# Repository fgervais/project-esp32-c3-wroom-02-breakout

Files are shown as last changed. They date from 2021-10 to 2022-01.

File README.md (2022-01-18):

# ESP32-C3-WROOM-02-N4 Breakout Board

## Objective

Make a low cost ESP32-C3 board that can run efficiently from 3x AA lithium
batteries.

## Power Consumption

### Deep Sleep (WROOM only)

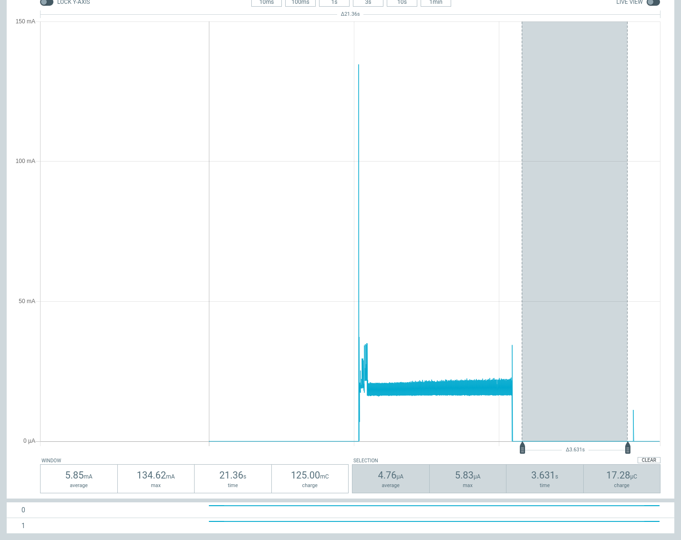
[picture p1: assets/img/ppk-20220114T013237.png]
DeepSleep


Watch the video (https://youtu.be/k5Rf_2-tnsE)

## Price

## PCB

## BOM

### Firmware

https://github.com/fgervais/project-idf-c3-test/tree/master/first_arduino_test

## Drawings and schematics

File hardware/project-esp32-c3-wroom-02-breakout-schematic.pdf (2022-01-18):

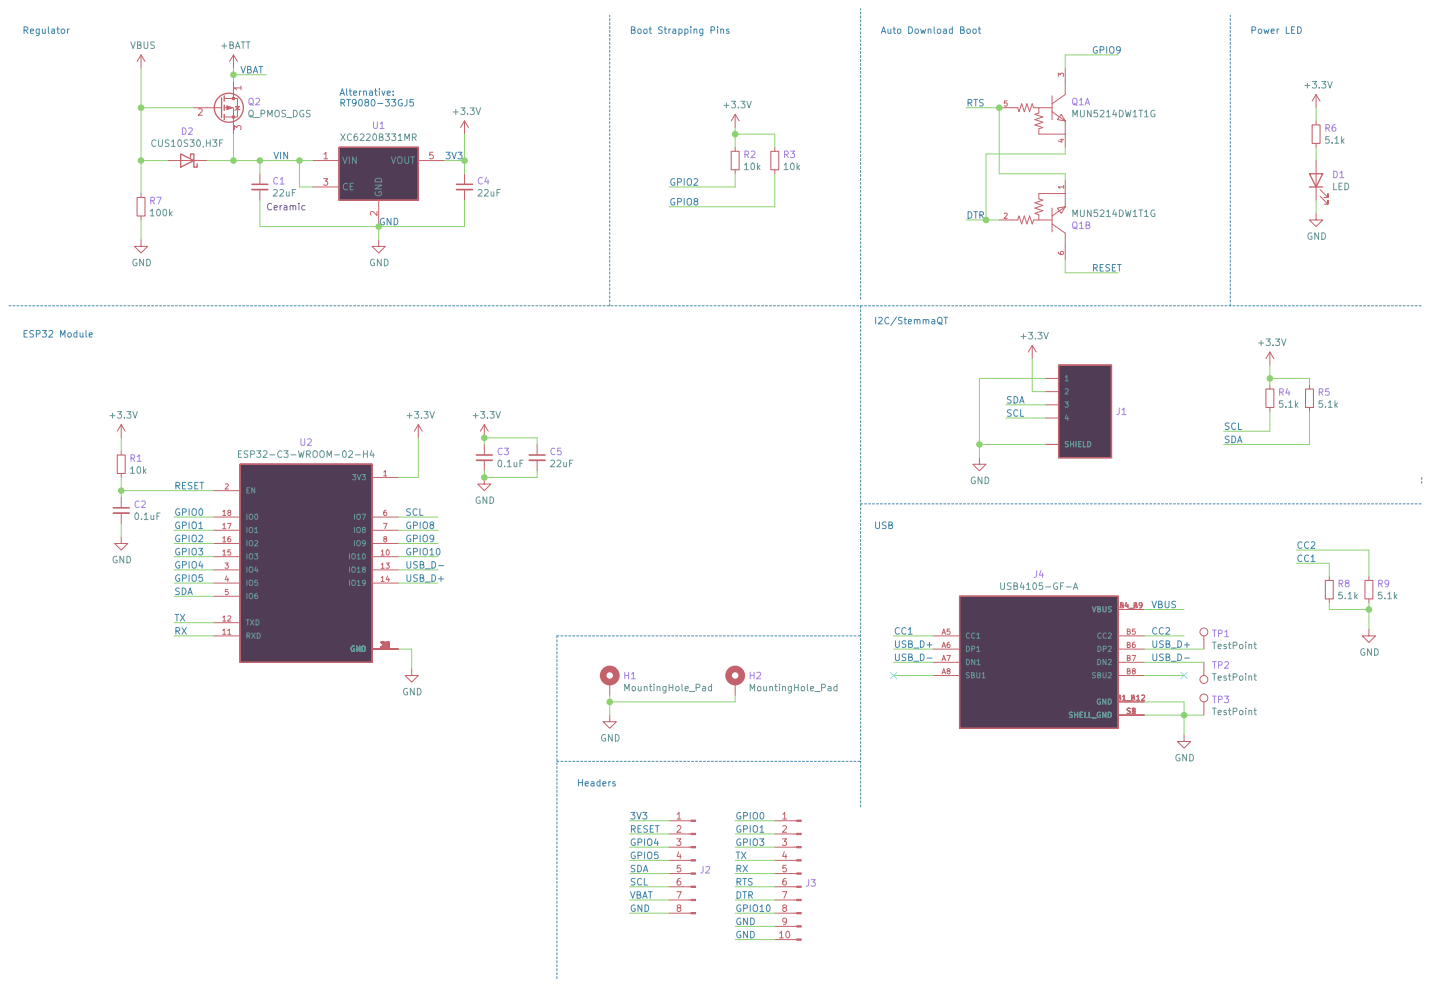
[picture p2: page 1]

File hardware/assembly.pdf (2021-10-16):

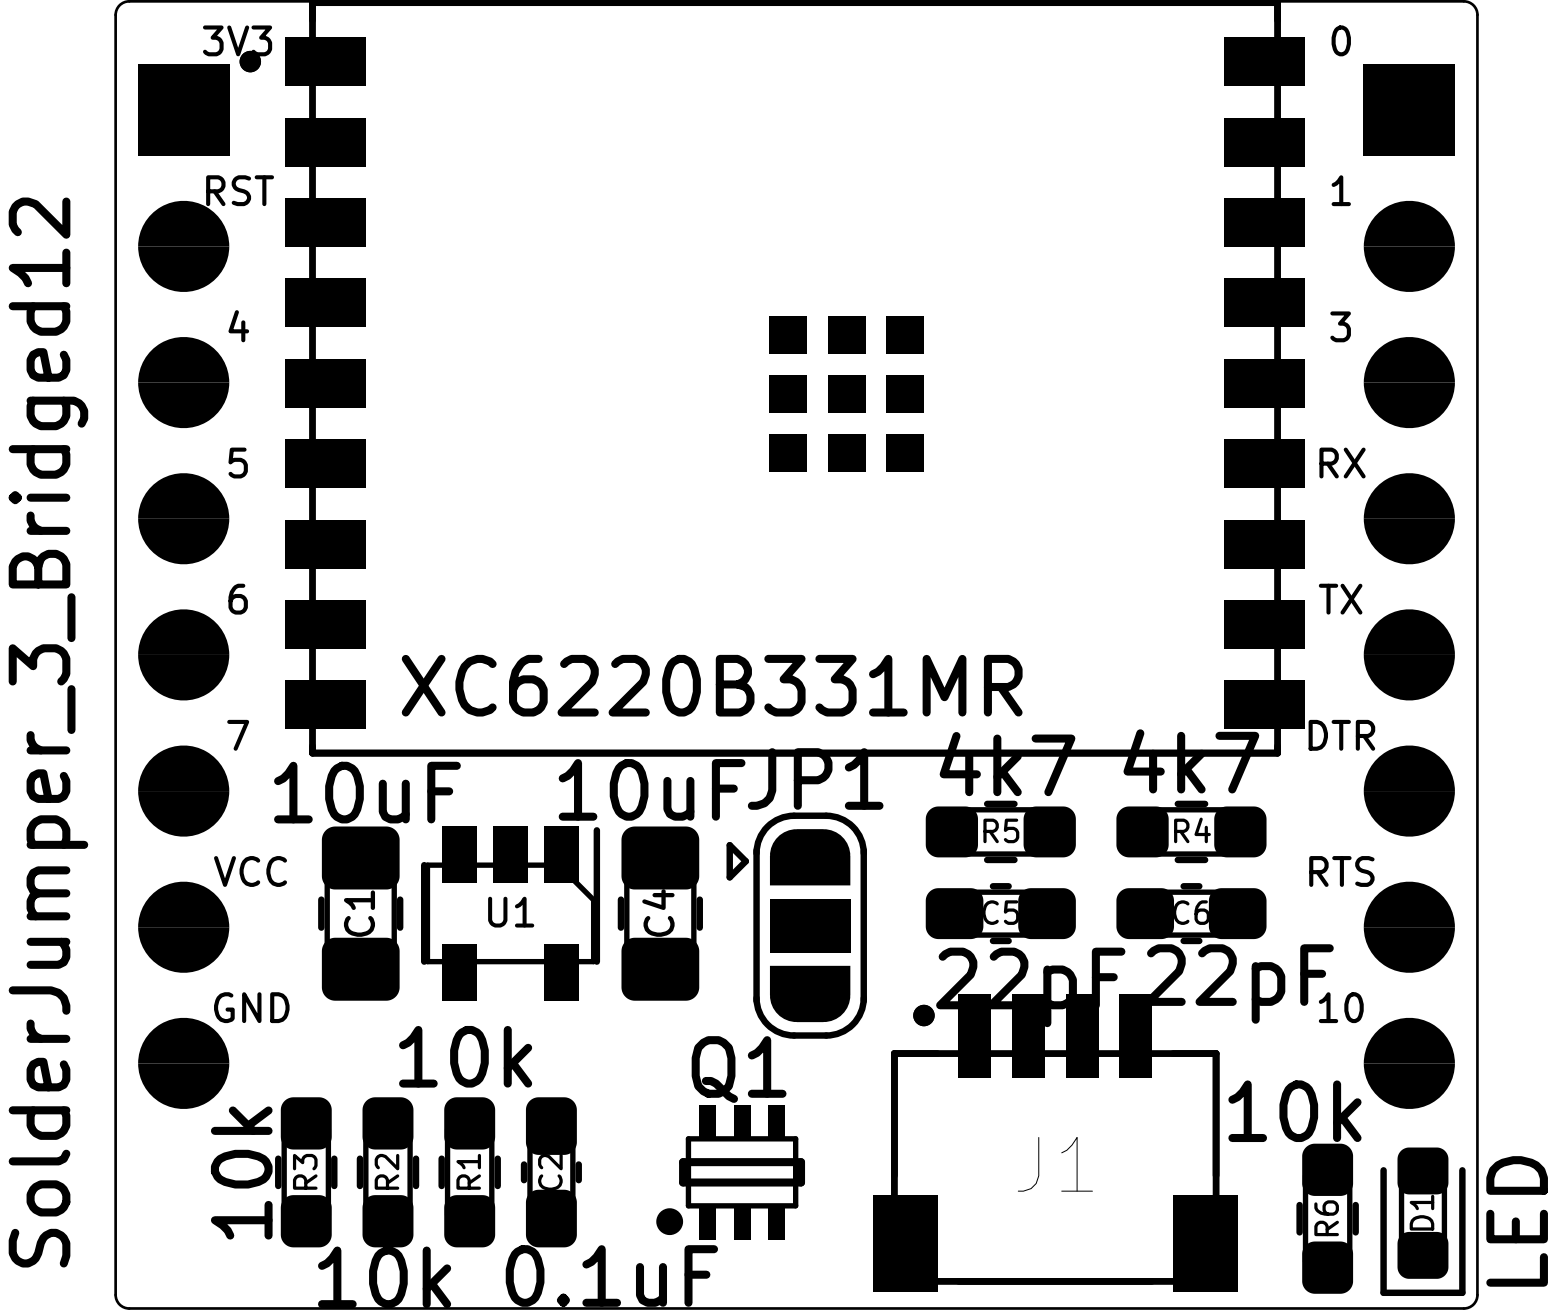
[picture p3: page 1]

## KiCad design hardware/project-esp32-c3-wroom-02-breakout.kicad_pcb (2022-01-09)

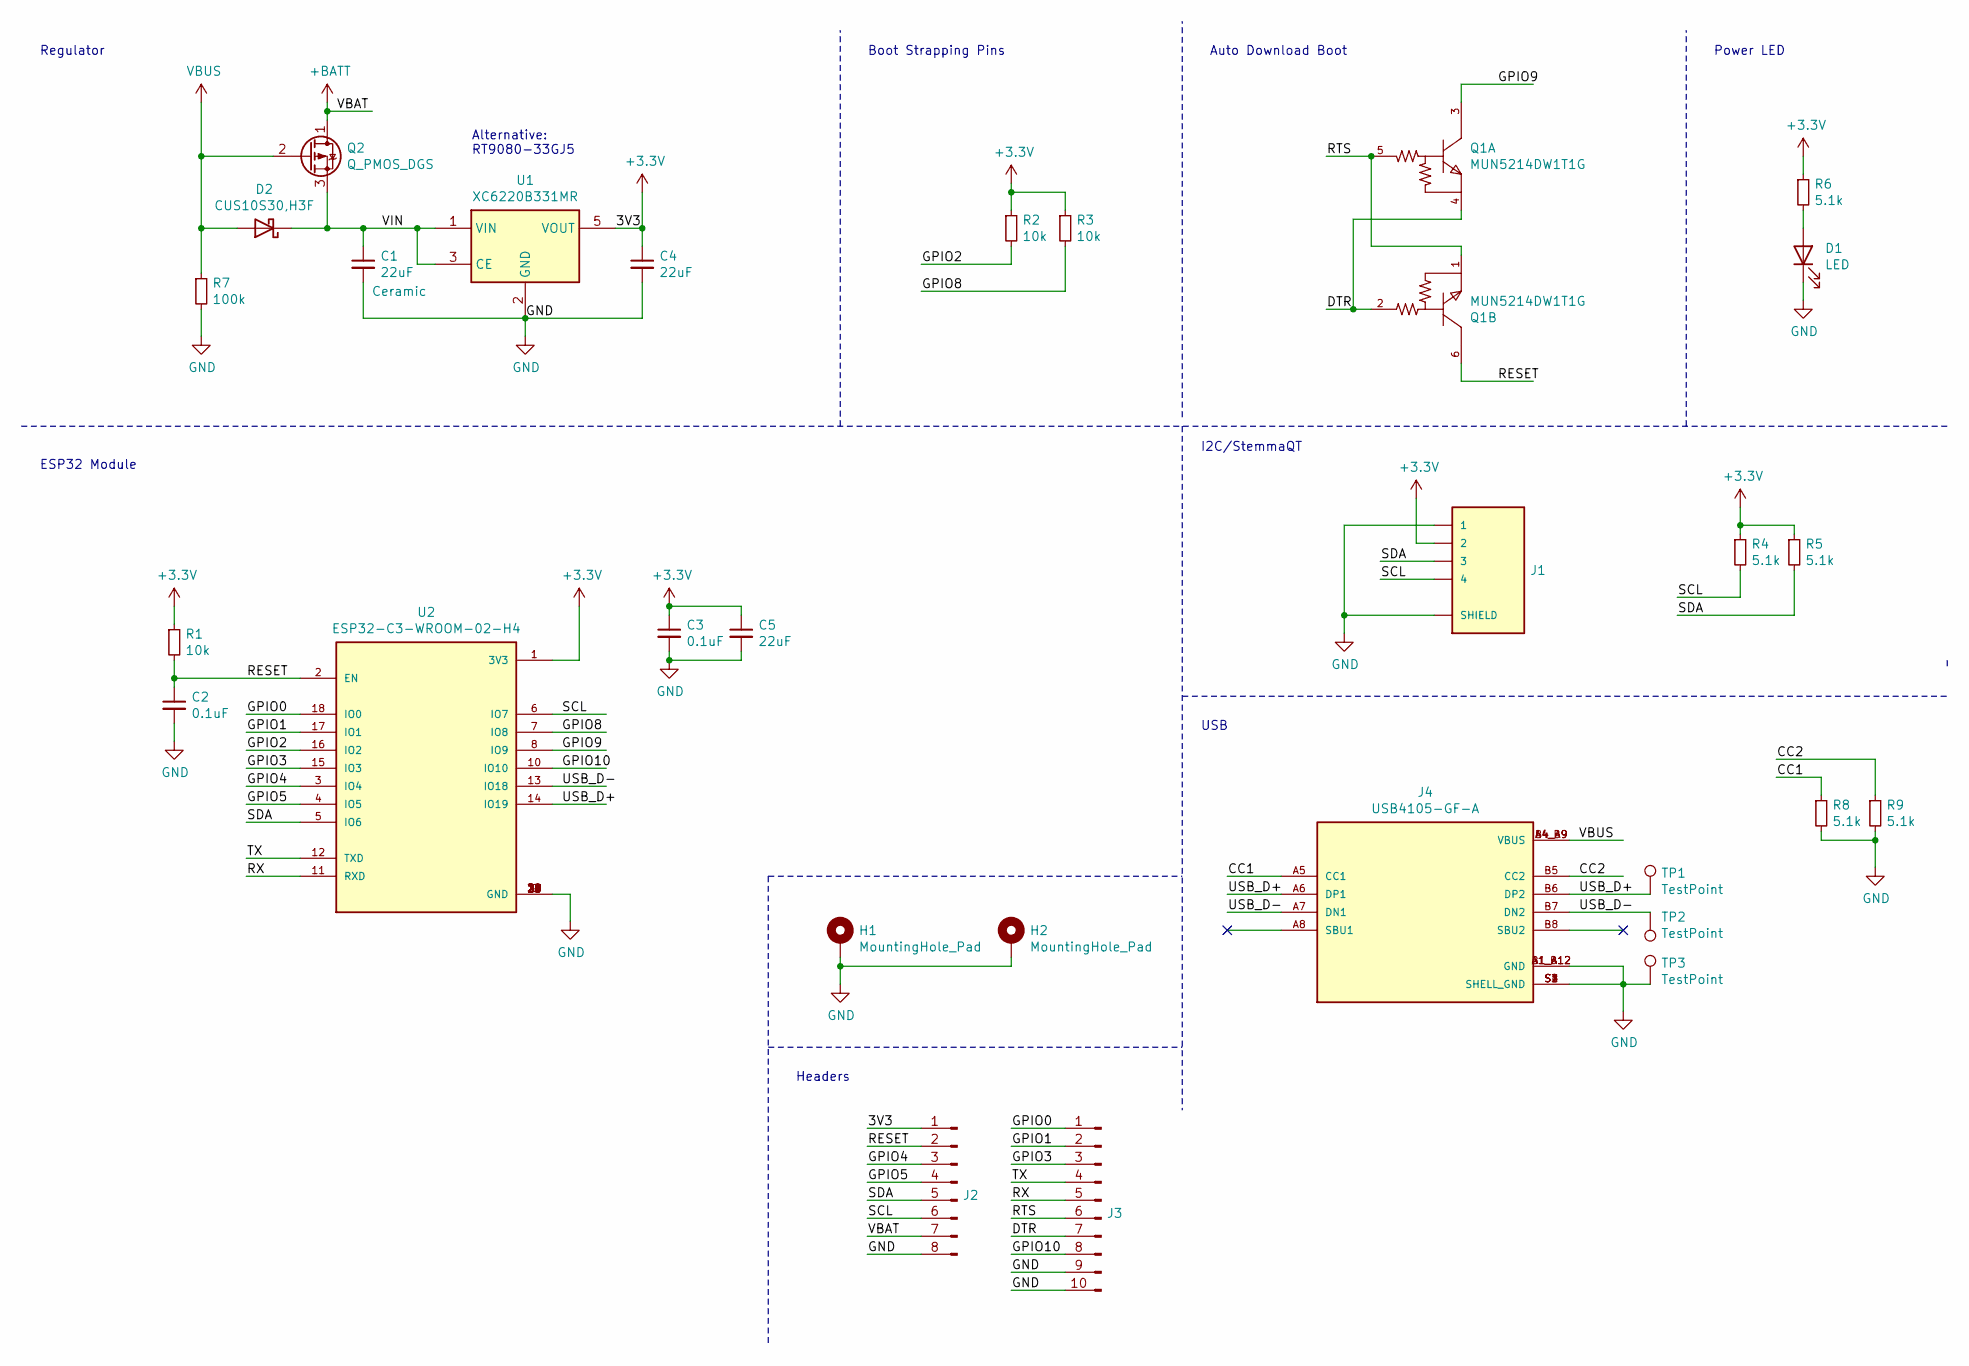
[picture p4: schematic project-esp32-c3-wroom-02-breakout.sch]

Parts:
C1, C4, C5: 22uF; C_0805_2012Metric_Pad1.18x1.45mm_HandSolder
C2, C3: 0.1uF; C_0603_1608Metric_Pad1.08x0.95mm_HandSolder
D1: LED; LED_0603_1608Metric
D2: CUS10S30,H3F‎; D_SOD-323
H1, H2: MountingHole_Pad; MountingHole_2.2mm_M2_ISO7380_Pad
J1: SM04B-SRSS-TB(LF)(SN); JST_SM04B-SRSS-TB(LF)(SN)
J2: Conn_01x08_Male; PinHeader_1x08_P2.54mm_Vertical
J3: Conn_01x10_Male; PinHeader_1x10_P2.54mm_Vertical
J4: USB4105-GF-A; GCT_USB4105-GF-A; PARTREV A3
Q1: MUN5214DW1T1G; On_Semiconductor-MUN5214DW1T1G-Manufacturer_Recommended
Q2: Q_PMOS_DGS; SOT50P160X60-6N
R1, R2, R3: 10k; R_0603_1608Metric_Pad0.98x0.95mm_HandSolder
R4, R5, R6, R8, R9: 5.1k; R_0603_1608Metric_Pad0.98x0.95mm_HandSolder
R7: 100k; R_0603_1608Metric_Pad0.98x0.95mm_HandSolder
TP1, TP2, TP3: TestPoint; TestPoint_Pad_D1.0mm
U1: XC6220B331MR; SOT-23-5
U2: ESP32-C3-WROOM-02-H4; MODULE_ESP32-C3-WROOM-02-H4; PARTREV V1.0

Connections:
+3V3: C3.1, C4.1, C5.1, J1.2, J2.1, R1.1, R2.1, R3.1, R4.1, R5.1, R6.1, U1.5 (VOUT), U2.1 (3V3)
+BATT: J2.7, Q2.1 (D)
/CC1: J4.A5 (CC1), R8.1
/CC2: J4.B5 (CC2), R9.1
/DTR: J3.7, Q1.2 (B), Q1.4 (E)
/GPIO0: J3.1, U2.18 (IO0)
/GPIO1: J3.2, U2.17 (IO1)
/GPIO2: R2.2, U2.16 (IO2)
/GPIO3: J3.3, U2.15 (IO3)
/GPIO4: J2.3, U2.3 (IO4)
/GPIO5: J2.4, U2.4 (IO5)
/GPIO8: R3.2, U2.7 (IO8)
/GPIO9: Q1.3 (C), U2.8 (IO9)
/GPIO10: J3.8, U2.10 (IO10)
/RESET: C2.1, J2.2, Q1.6 (C), R1.2, U2.2 (EN)
/RTS: J3.6, Q1.1 (E), Q1.5 (B)
/RX: J3.5, U2.11 (RXD)
/SCL: J1.4, J2.6, R4.2, U2.6 (IO7)
/SDA: J1.3, J2.5, R5.2, U2.5 (IO6)
/TX: J3.4, U2.12 (TXD)
/USB_D+: J4.A6 (DP1), J4.B6 (DP2), TP1.1, U2.14 (IO19)
/USB_D-: J4.A7 (DN1), J4.B7 (DN2), TP2.1, U2.13 (IO18)
/VIN: C1.1, D2.1 (K), Q2.3 (S), U1.1 (VIN), U1.3 (CE)
GND: C1.2, C2.2, C3.2, C4.2, C5.2, D1.1 (K), H1.1, H2.1, J1.1, J1.S1 (SHIELD), J1.S2 (SHIELD), J2.8, J3.9, J3.10, J4.A1_B12 (GND), J4.B1_A12 (GND), J4.S1 (SHELL_GND), J4.S2 (SHELL_GND), J4.S3 (SHELL_GND), J4.S4 (SHELL_GND), R7.2, R8.2, R9.2, TP3.1, U1.2 (GND), U2.9 (GND), U2.19 (GND), U2.20 (GND), U2.21 (GND), U2.22 (GND), U2.23 (GND), U2.24 (GND), U2.25 (GND), U2.26 (GND), U2.27 (GND), U2.28 (GND), U2.29 (GND), U2.30 (GND), U2.31 (GND), U2.32 (GND), U2.33 (GND), U2.34 (GND), U2.35 (GND), U2.36 (GND), U2.37 (GND), U2.38 (GND), U2.39 (GND)
unnamed: D1.2 (A), R6.2
VBUS: D2.2 (A), J4.A4_B9 (VBUS), J4.B4_A9 (VBUS), Q2.2 (G), R7.1

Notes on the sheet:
Regulator
Boot Strapping Pins
Auto Download Boot
Headers
ESP32 Module
I2C/StemmaQT
Power LED
USB
Alternative: ‎RT9080-33GJ5‎

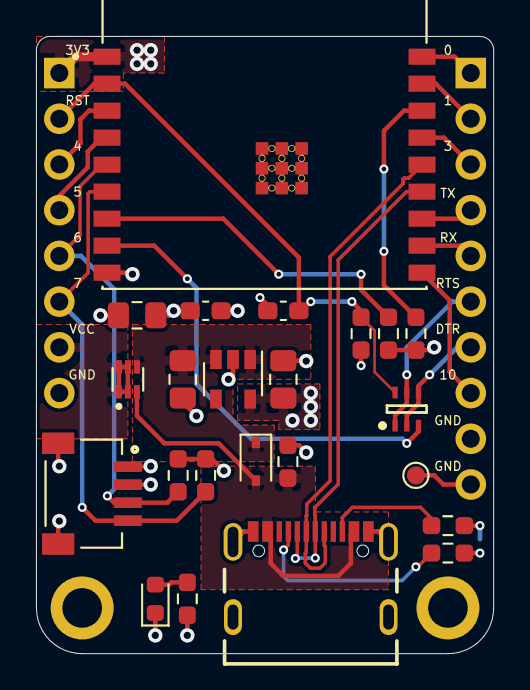
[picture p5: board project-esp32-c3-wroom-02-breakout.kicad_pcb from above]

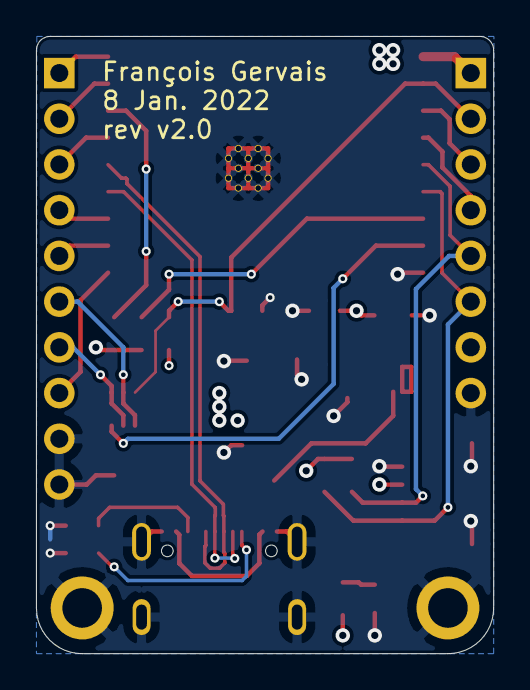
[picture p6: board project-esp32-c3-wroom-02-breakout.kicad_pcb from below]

Board: 4 copper layers, 25.4 x 34.3 mm, 27 parts (2 on the bottom side), 26 nets.

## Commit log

2021-09-17 Use wrover breakout project as base
    [esp32-wrover-breakout.kicad_pcb, esp32-wrover-breakout.sch, project-esp32-c3-wroom-02-breakout.kicad_pcb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]
2021-09-24 Schematic ready
    [project-esp32-c3-wroom-02-breakout.sch]
2021-09-25 First placement done
    [project-esp32-c3-wroom-02-breakout.kicad_pcb, project-esp32-c3-wroom-02-breakout.sch]
2021-09-25 Routing done
    [project-esp32-c3-wroom-02-breakout.kicad_pcb, project-esp32-c3-wroom-02-breakout.sch]
2021-10-02 Fix reg cap values in schematic
    [project-esp32-c3-wroom-02-breakout.sch]
2021-10-16 Add assembly document
    [project-esp32-c3-wroom-02-breakout.kicad_pcb]
2021-10-17 Change visible layers
    [project-esp32-c3-wroom-02-breakout.kicad_pcb]
2022-01-02 Fix inverted RX/TX labels
    [project-esp32-c3-wroom-02-breakout.kicad_pcb]
2022-01-06 Add p-mosfet, schottky and usb connector to project
2022-01-06 Add USB port to schematic
    [project-esp32-c3-wroom-02-breakout.sch]
2022-01-08 Annotate schematic
    [project-esp32-c3-wroom-02-breakout.sch]
2022-01-08 Change schottky footprint
    [project-esp32-c3-wroom-02-breakout.sch]
2022-01-08 Change mounting hole to M2
    [project-esp32-c3-wroom-02-breakout.sch]
2022-01-08 Change schottky footprint for non handsolder
    [project-esp32-c3-wroom-02-breakout.sch]
2022-01-08 Power + USB route
    [project-esp32-c3-wroom-02-breakout.kicad_pcb, project-esp32-c3-wroom-02-breakout.sch]
2022-01-09 Add version of previous commit
    [project-esp32-c3-wroom-02-breakout.kicad_pcb]
2022-01-18 Export schematic
